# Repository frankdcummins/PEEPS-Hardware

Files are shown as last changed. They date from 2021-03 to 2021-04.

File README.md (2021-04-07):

# PEEPS-Hardware
Repository for the Northwestern University Segal Design School Students' Positive End Expiration Pressure (PEEP) project hardware.

## Description
This printed circuit board (PCB) is designed to make use of NXP's [MPXV7002 Integrated Silicon Pressure Sensor](https://www.nxp.com/docs/en/data-sheet/MPXV7002.pdf) to measure and record pressure at as many as two points in the PEEP apparatus. It also includes a simple driver for an [air pump](https://www.adafruit.com/product/4699) that can generate up to 2.5 L/min of air flow. The microcontroller takes pressure readings at 100Hz and transmits them over a serial UART port to be analyzed in real-time or offline. The controller can activate the air pump through this serial interface as well. <br><br>This board will be used to verify the student design's functionality against the industry standard. It uses primarily through-hole components for ease and speed of assembly.

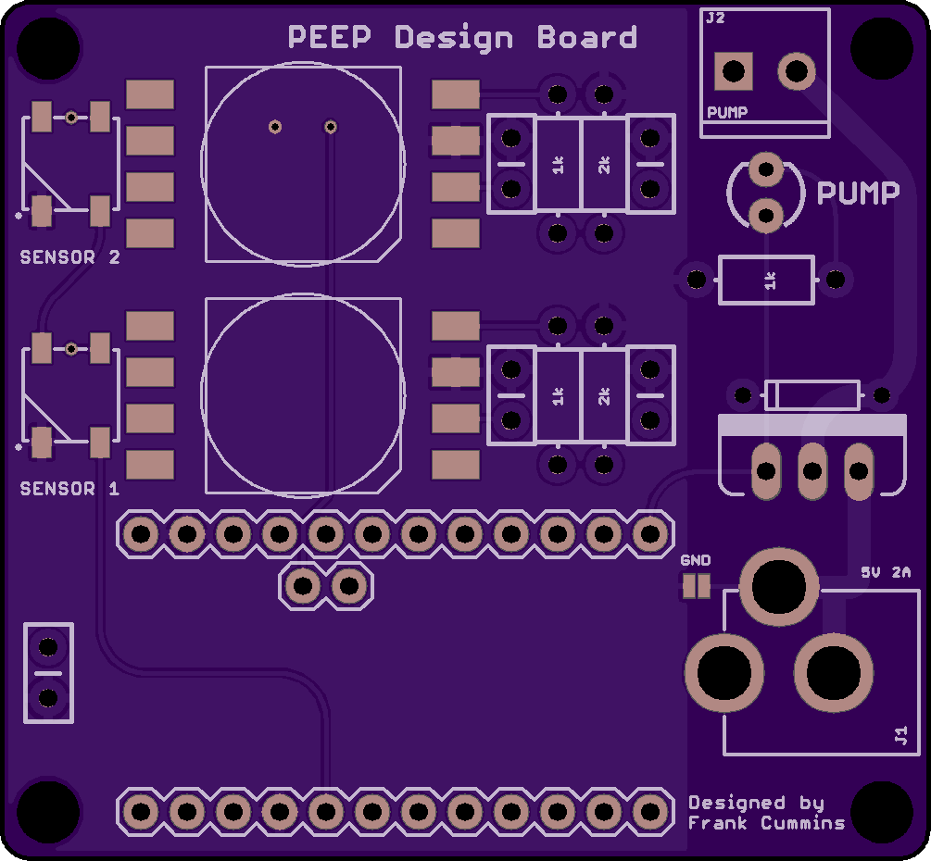
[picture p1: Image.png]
PCB-Front


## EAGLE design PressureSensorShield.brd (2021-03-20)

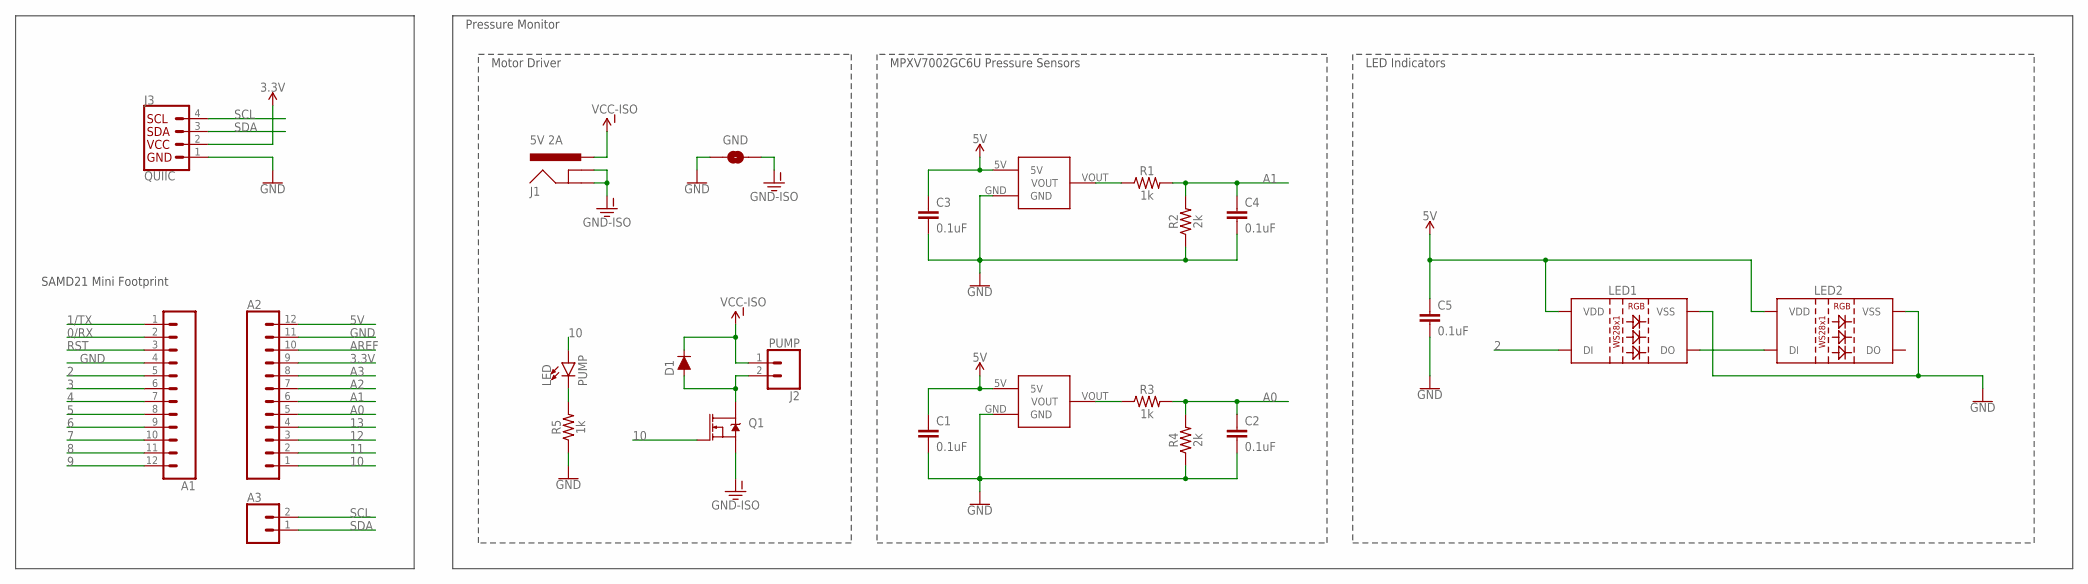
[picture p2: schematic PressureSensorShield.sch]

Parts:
A1, A2: CONN_12; 1X12
A3: CONN_02; 1X02
C1, C2, C3, C4, C5: 0.1uF; CAP-PTH-SMALL-KIT
D1: DIODE-KIT; DIODE-1N4148-KIT
GND: JUMPER-SMT_2_NO_NO-SILK; SMT-JUMPER_2_NO_NO-SILK
J1: 5V 2A; POWER_JACK_PTH
J2: PUMP; SCREWTERMINAL-3.5MM-2
J3: QUIIC; JST04_1MM_RA
LED: PUMP; LED_3MM
LED1, LED2: WS2812B
Q1: MOSFET-NCH-FQP30N06L; TO220V
R1, R3, R5: 1k; AXIAL-0.3-KIT
R2, R4: 2k; AXIAL-0.3-KIT
SENSOR: SENSOR 1; SMALL_OUTLINE
SENSOR2: SENSOR 2; SMALL_OUTLINE

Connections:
0/RX: A1.2
1/TX: A1.1
2: A1.5, LED1.4 (DI)
3: A1.6
3.3V: A2.9, J3.2
4: A1.7
5: A1.8
5V: A2.12, C1.1, C3.1, C5.1, LED1.1 (VDD), LED2.1 (VDD), SENSOR.5V, SENSOR2.5V
6: A1.9
7: A1.10
8: A1.11
9: A1.12
10: A2.1, LED.A, Q1.1 (G)
11: A2.2
12: A2.3
13: A2.4
A0: A2.5, C2.1, R3.P$2 (2), R4.P$2 (2)
A1: A2.6, C4.1, R1.P$2 (2), R2.P$2 (2)
A2: A2.7
A3: A2.8
AREF: A2.10
GND: A1.4, A2.11, C1.2, C2.2, C3.2, C4.2, C5.2, GND.1, J3.1, LED1.3 (VSS), LED2.3 (VSS), R2.P$1 (1), R4.P$1 (1), R5.P$1 (1), SENSOR.GND, SENSOR2.GND
GND-ISO: GND.2, J1.GND, J1.GNDBREAK, Q1.3 (S)
unnamed: LED.K (C), R5.P$2 (2)
unnamed: R1.P$1 (1), SENSOR2.VOUT
unnamed: LED1.2 (DO), LED2.4 (DI)
unnamed: R3.P$1 (1), SENSOR.VOUT
unnamed: D1.A, J2.2, Q1.2 (D)
RST: A1.3
SCL: A3.2, J3.4
SDA: A3.1, J3.3
VCC-ISO: D1.C, J1.PWR, J2.1

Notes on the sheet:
LED Indicators
Pressure Monitor
SAMD21 Mini Footprint
Motor Driver
MPXV7002GC6U Pressure Sensors

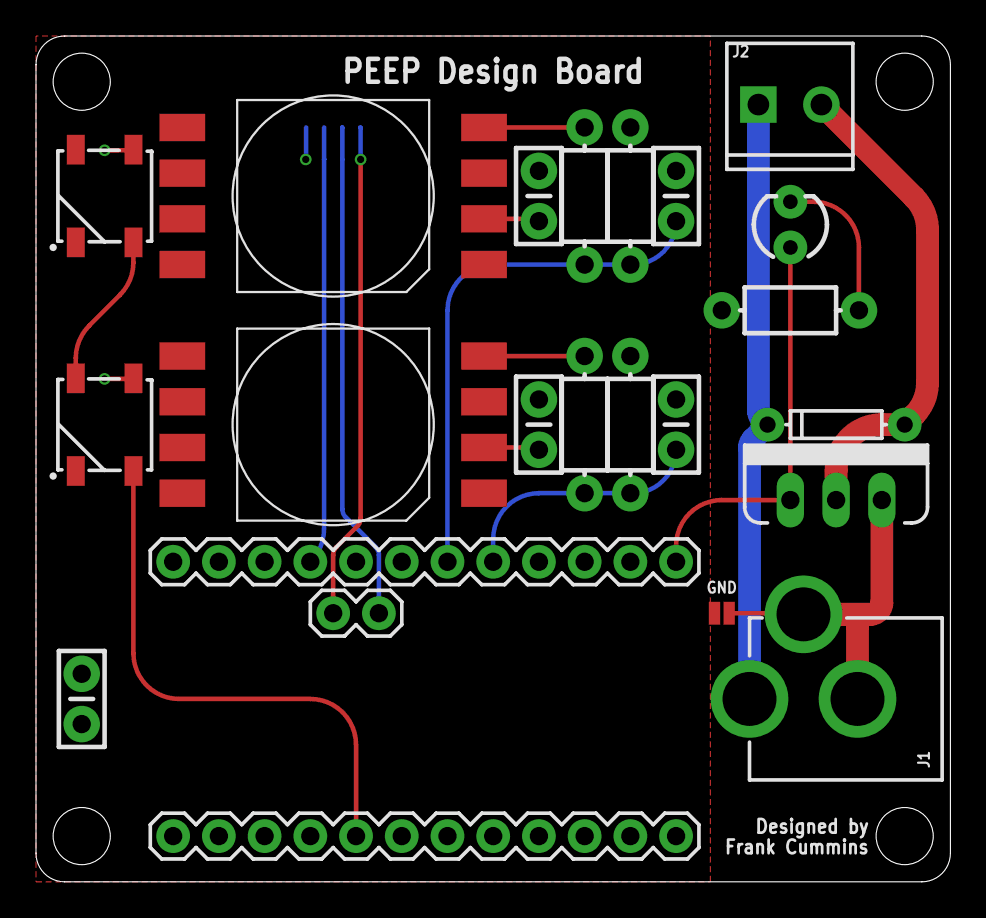
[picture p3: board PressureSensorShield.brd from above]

Board: 2 copper layers, 50.8 x 47.0 mm, 24 parts (1 on the bottom side), 16 nets.

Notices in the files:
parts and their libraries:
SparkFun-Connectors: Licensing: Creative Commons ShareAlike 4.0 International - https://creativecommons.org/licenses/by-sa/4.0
